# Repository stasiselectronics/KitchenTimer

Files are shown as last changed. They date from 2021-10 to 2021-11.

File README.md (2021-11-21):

# KitchenTimer

Welcome to the source files!

Here you can find all the files and folders needed to replicate or redesign this project!

This circuit board is designed to bring together a WiFi enabled microcontroller with a 4 character segmented LED display. 

# Current Status

I have recieved the first round of boards and began prototyping the electronics assembly.

The firmwware has some more work needed before it can display numbers and adjust brightness.

The board has a few things that need to be fixed before the next round of PCB fabrication.

I should try and get a PCB order soon, before the end of the year.

# Documentation

Not a lot of documentation except for the source files. If you have a question regarding this design, don't hesitate to open an issue on this repository

# Licenses

The design files for this project are covered under 

CERN-OHL-S

Cern Open Hardware License - Strongly Reciprocal

[View Full License Text](https://ohwr.org/cern_ohl_s_v2.pdf)

## Folder Structure

The project is separated into main categories at the root of the project folder. I use "Hardware Files" to hold all of the printed circuit board design files. I also use some other descriptive names and keep them consistent amongst projects:

- **Enclosure Files** : 3D printed or somehow otherwise fabricated. All the files needed for the box the project might end up in.
- **Firmware Files** : The code for any microcontrollers that might end up on the boards. 
- **Mechanical Files** : Any CAD files for fabricating parts for the project. 

## Libraries

The KiCAD project has a project specific library that can be used for keeping the custom designed footprints and symbols.

By default it isn't a global library, so if you would like to use the footprints or symbols in another project be sure to change it to a "global" library.

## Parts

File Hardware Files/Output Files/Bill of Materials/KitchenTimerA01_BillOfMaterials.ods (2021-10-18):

KitchenTimer |  |  | Bill Of Materials
PCBA Revision |  |  | A01
Item | Qty | Designator | Value | Part 1 MF | Part 1 MPN | Part 1 Ordering Code
1 | 2 | C10 C12 | 220nF 1206 Capacitor | YAGEO | CC1206KKX7R9BB224 | C107186 | ☐
2 | 8 | C1 C3-C8 C11 | 1 uF 0805 Capacitor | Samsung Electro-Mechanics | CL31B105KCHNNNE | C13832 | ☐
3 | 3 | C2 C9 C13 | 10uF 1206 Capacitor | Samsung Electro-Mechanics | CL31B106KAHNNNE | C14860 | ☐
4 | 1 | J1 | 2.54mm Male PCB Header | Ckmtw(Shenzhen Cankemeng) | B-2100S04P-A110 | C124378 | ☐
5 | 1 | J2 | MicroUSB | Korean Hroparts Elec | U-F-M5DD-Y-L | C91146 | ☐
6 | 1 | LED1 | Blue 4 Char LED 0.56" (CA) | SUNLIGHT | SLR0564DBA4BD | C225950 | ☐
7 | 5 | Q1-Q5 | PFET 1V 250uA 4A SOT-23 | Diodes Incorporated | DMG3415U-7 | C96616 | ☐
8 | 6 | R1 R2 R8-R11 | 10k 0805 Resistor | YAGEO | RC0805FR-0710KL | C84376 | ☐
9 | 5 | R3-R7 | 10k 0603 Resistor | YAGEO | RC0603FR-0710KL | C98220 | ☐
10 | 9 | R12-R20 | 10R 0603 Resistor | YAGEO | RC0603FR-0710RL | C109318 | ☐
11 | 2 | SW1 SW2 | SPST 50mA @ 12VDC SMD, 6.0x3.5x5.0mm | HYP (Hongyuan Precision) | 1TS002B-1900-4300-CT | C318823 | ☐
12 | 4 | SW3-SW6 | SPST 50mA @ 12VDC SMD, 6.0x6.0x5.0mm | HYP (Hongyuan Precision) | 1TS005F-2500-5001 | C255812 | ☐
13 | 1 | U4 | 15V 1.25V @ 1A Fixed 3.3V SOT-223 (LDO) | Diodes Incorporated | AZ1117H-3.3TRE1 | C92517 | ☐
14 | 1 | U1 | ESP 8266 SMD Module | Espressif Systems | ESP-WROOM-02D | C473007 | ☐
15 | 2 | U2 U3 | 3.3V/5V Shift Register SOIC 16 | Nexperia | 74HC595D | C5947 | ☐

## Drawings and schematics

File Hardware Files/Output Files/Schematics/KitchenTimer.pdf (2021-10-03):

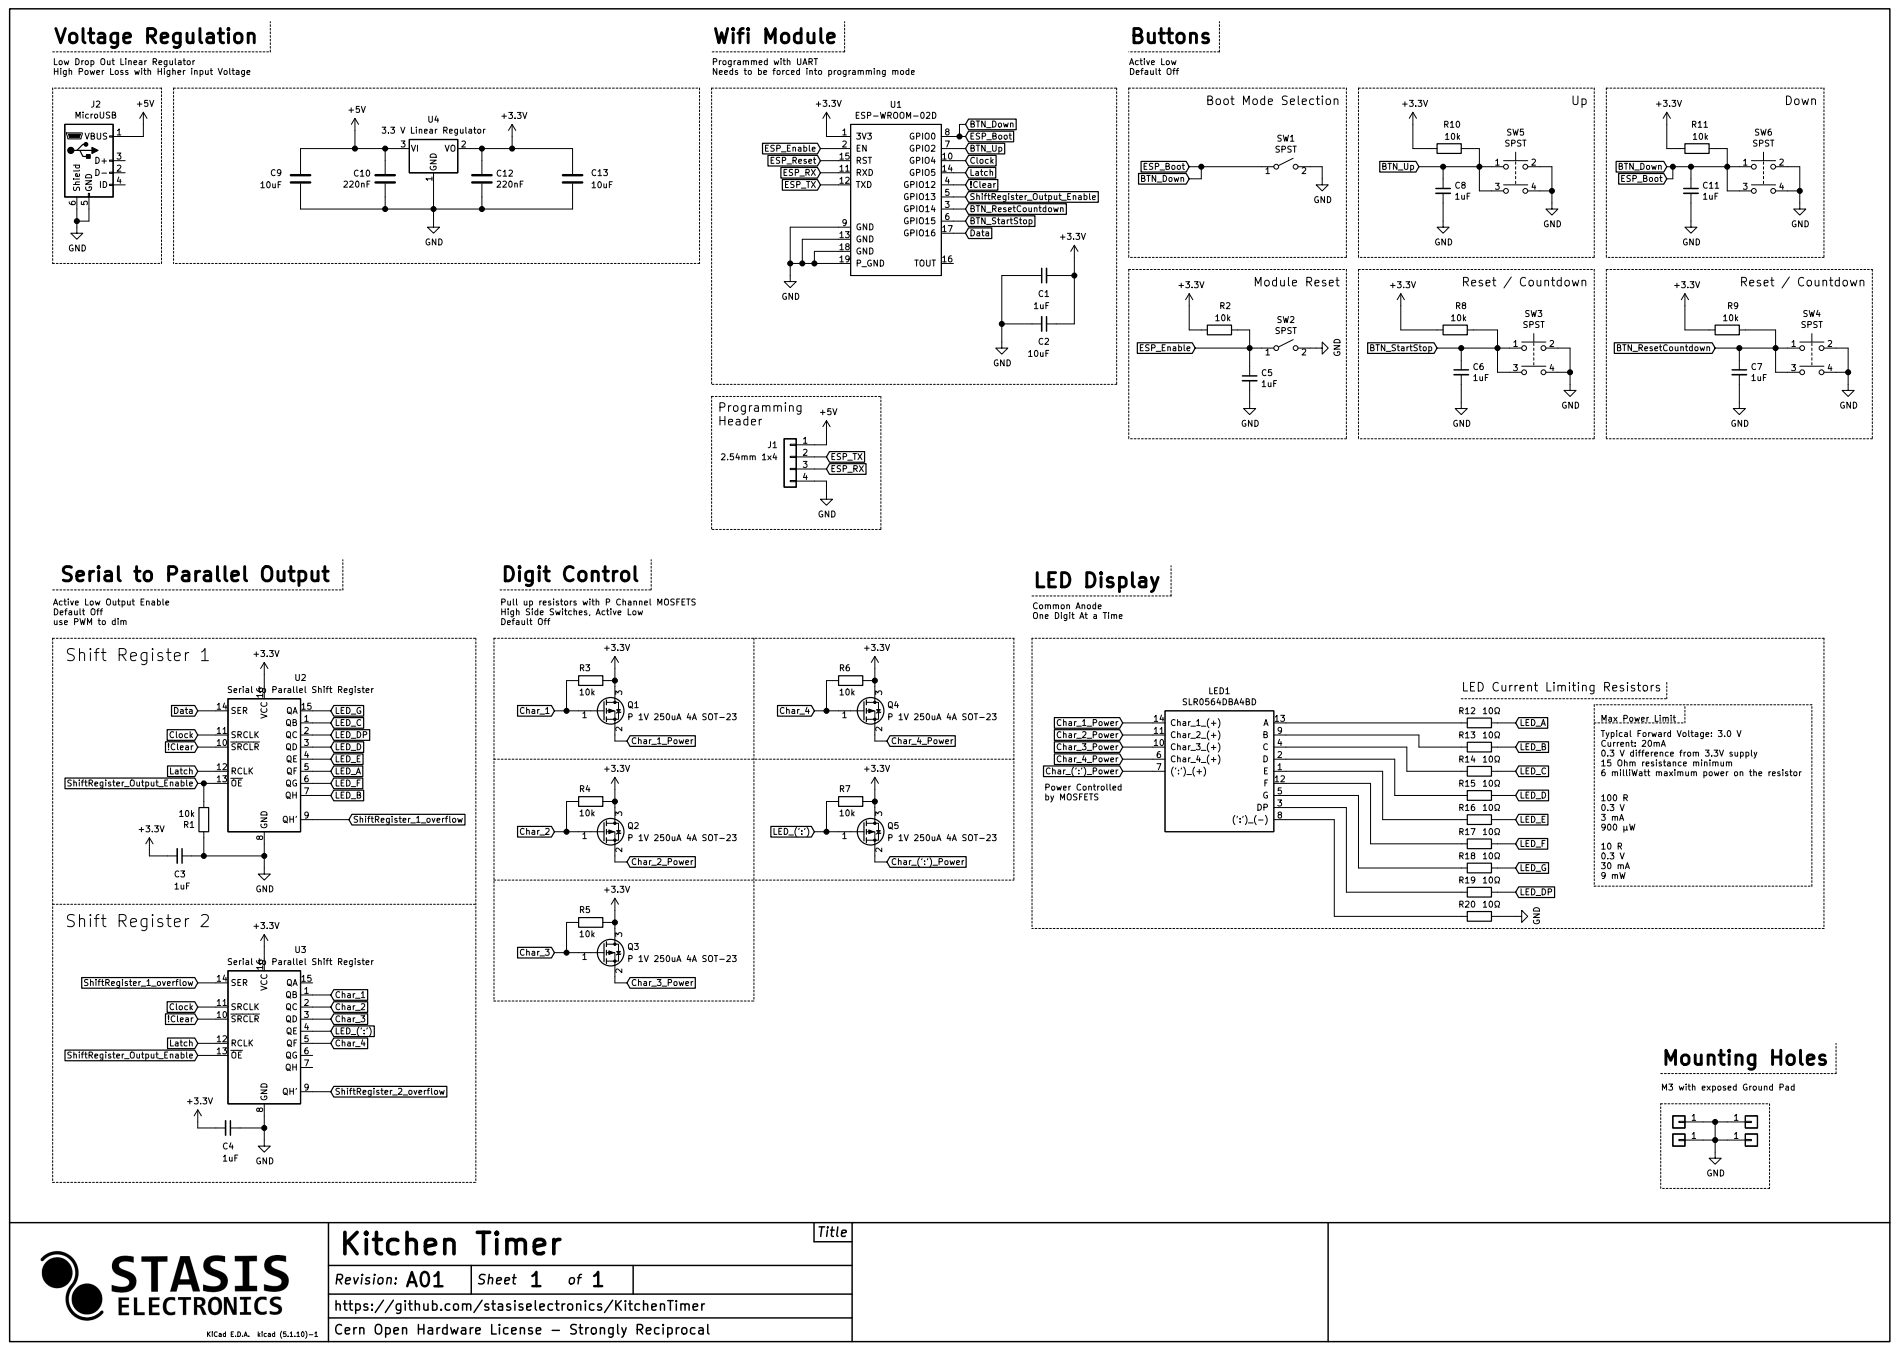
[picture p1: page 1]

Low Drop Out Linear Regulator
High Power Loss with Higher input Voltage

Programmed with UART
Needs to be forced into programming mode

8 QH' 9 U2 Serial to Parallel Shift Register GND GND

6 milliWatt maximum power on the resistor Max Power Limit Serial to Parallel Output

High Side Switches, Active Low

Common Anode One Digit At a Time

LED Current Limiting Resistors

Typical Forward Voltage: 3.0 V Current: 20mA

0.3 V difference from 3.3V supply 15 Ohm resistance minimum

8 QH' 9 U3 Serial to Parallel Shift Register

M3 with exposed Ground Pad

Revision:
https://github.com/stasiselectronics/KitchenTimer

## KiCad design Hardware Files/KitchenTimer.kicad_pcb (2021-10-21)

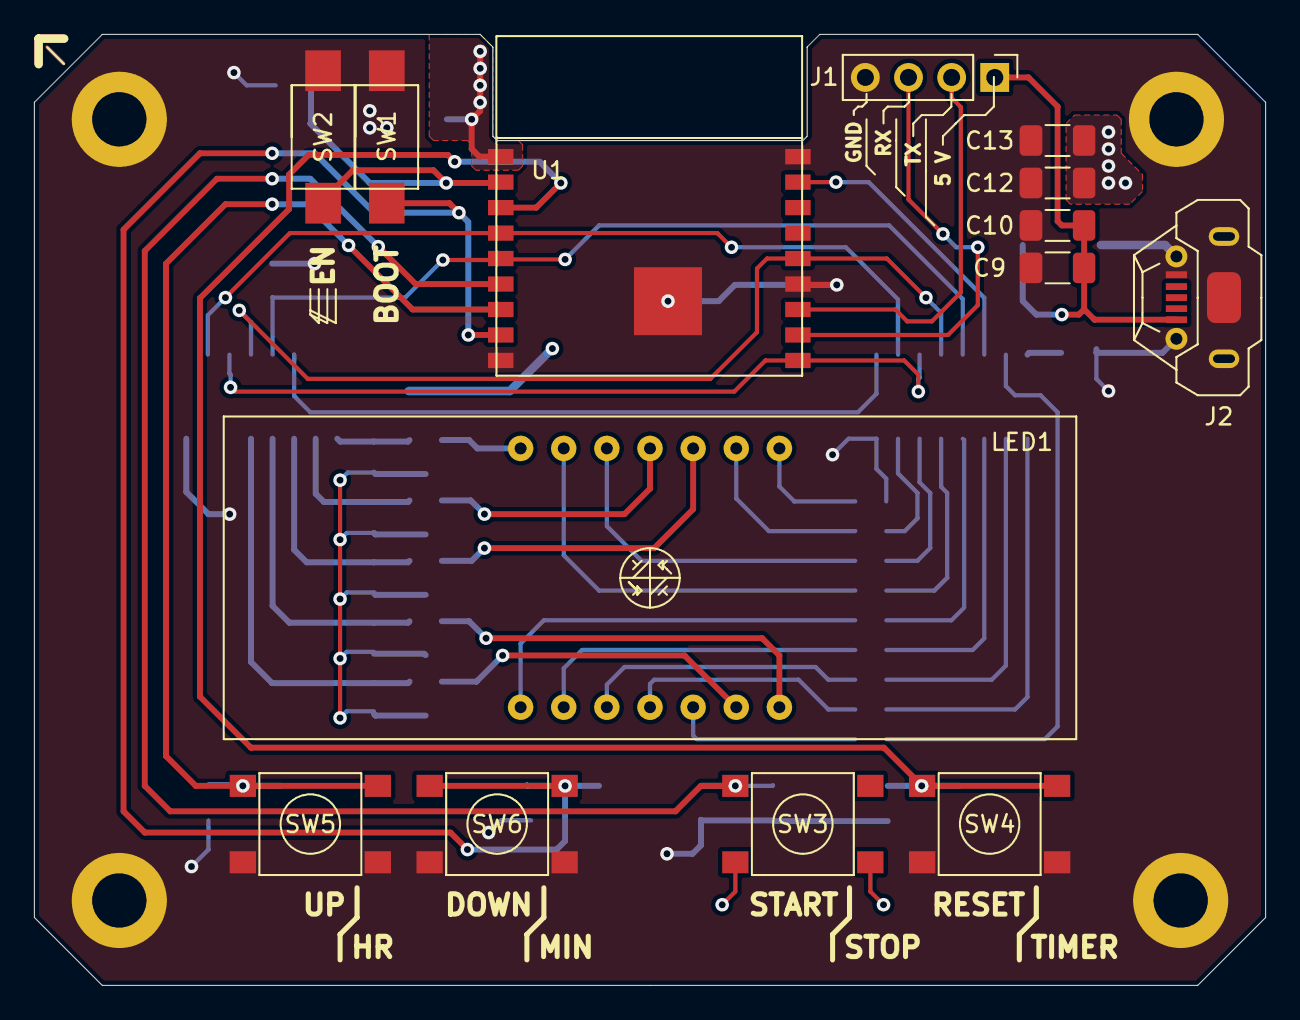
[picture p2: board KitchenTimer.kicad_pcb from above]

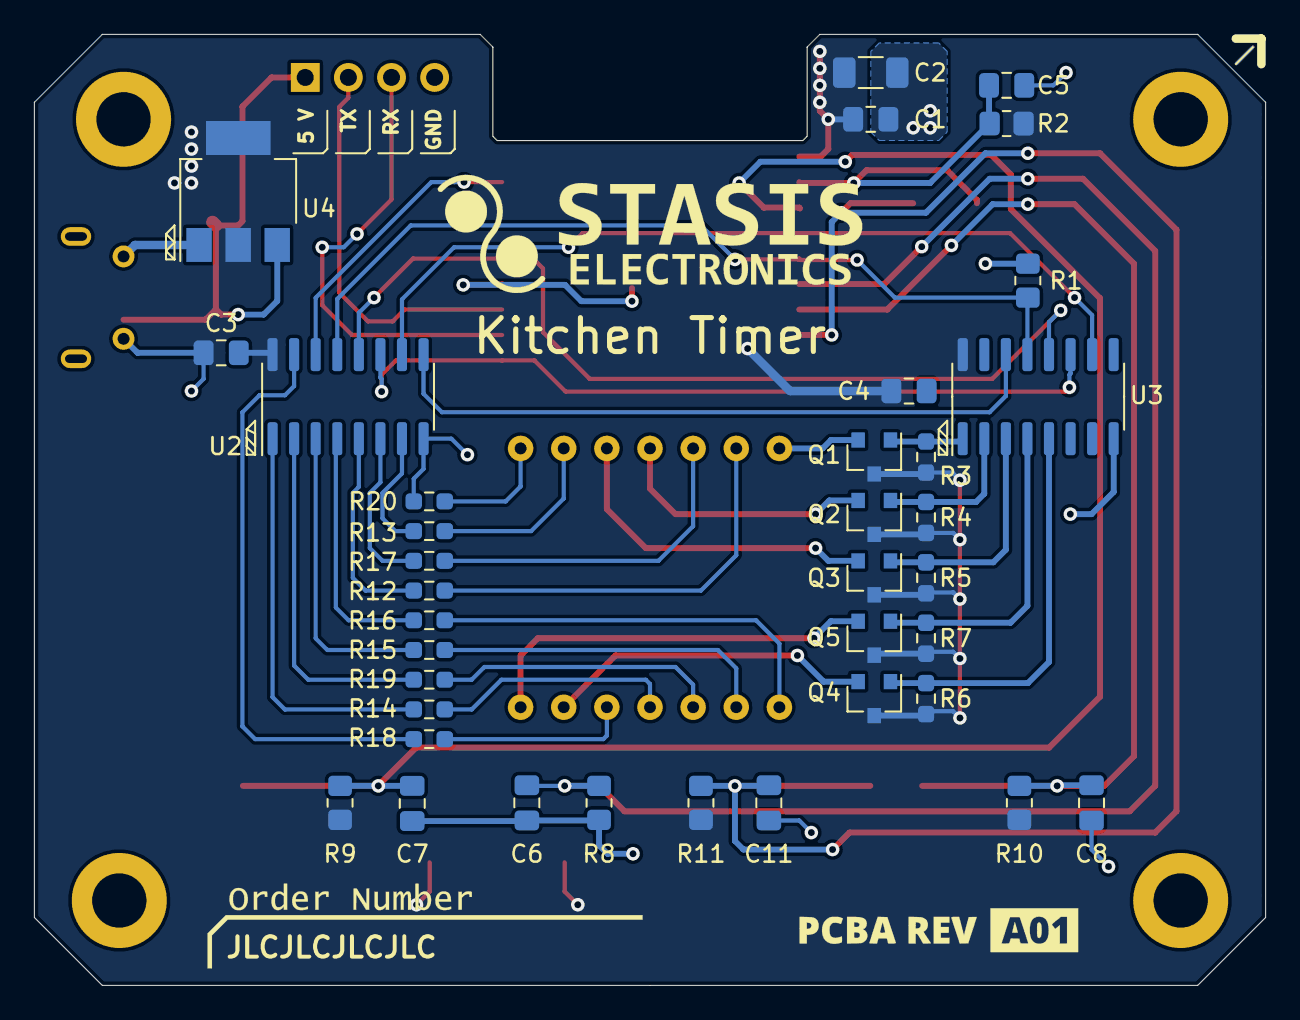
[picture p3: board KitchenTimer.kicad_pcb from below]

Board: 2 copper layers, 72.5 x 56.0 mm, 55 parts (37 on the bottom side), 43 nets.

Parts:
C1, C3, C4, C5, C6, C7, C8, C11: 1uF; C_0805_2012Metric_Pad1.18x1.45mm_HandSolder
C2, C9, C13: 10uF; C_1206_3216Metric_Pad1.33x1.80mm_HandSolder
C10, C12: 220nF; C_1206_3216Metric_Pad1.33x1.80mm_HandSolder
J1: 2.54mm 1x4; PinHeader_1x04_P2.54mm_Vertical
J2: MicroUSB; U-F-M5DD-Y-L
J3, J4, J5, J6: Mounting Hole; MountingHole_3.2mm_M3_DIN965_Pad
LED1: Blue 4 Char LED 0.56" (CA); SLR0564DBA4BD
Q1, Q2, Q3, Q4, Q5: PFET 1V 250uA 4A SOT-23; SOT-23
R1, R2, R8, R9, R10, R11: 10k; R_0805_2012Metric_Pad1.20x1.40mm_HandSolder
R3, R4, R5, R6, R7: 10k; R_0603_1608Metric_Pad0.98x0.95mm_HandSolder
R12, R13, R14, R15, R16, R17, R18, R19, R20: 10Ω; R_0603_1608Metric_Pad0.98x0.95mm_HandSolder
SW1, SW2: SPST; PTS636_SM25F_SMTR_LFS
SW3, SW4, SW5, SW6: SPST; PTS645SK50SMTR92LFS
U1: ESP-WROOM-02D
U2, U3: Serial to Parallel Shift Register; SOIC-16_3.9x9.9mm_P1.27mm
U4: 3.3 V Linear Regulator; SOT-223-3_TabPin2

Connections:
!Clear: U1.4, U2.10, U3.10
+3V3: C1.2, C2.1, C3.1, C4.1, C12.1, C13.1, Q1.3, Q2.3, Q3.3, Q4.3, Q5.3, R2.1, R3.2, R4.2, R5.2, R6.2, R7.2, R9.1, R10.1, R11.1, SW3.2, SW3.4, U1.1, U2.16, U3.16, U4.2
+5V: C9.1, C10.1, J1.1, J2.1, U4.3
BTN_Down: C11.1, R11.2, SW1.1, SW6.1, SW6.3, U1.8
BTN_ResetCountdown: C7.1, R9.2, SW4.1, SW4.3, U1.3
BTN_StartStop: C6.1, R8.1, SW3.1, SW3.3, U1.6
BTN_Up: C8.1, R10.2, SW5.1, SW5.3, U1.7
Char_1: Q1.1, R3.1, U3.1
Char_1_Power: LED1.14, Q1.2
Char_2: Q2.1, R4.1, U3.2
Char_2_Power: LED1.11, Q2.2
Char_3: Q3.1, R5.1, U3.3
Char_3_Power: LED1.10, Q3.2
Char_4: Q4.1, R6.1, U3.5
Char_4_Power: LED1.6, Q4.2
Char_(':')_Power: LED1.7, Q5.2
Clock: U1.10, U2.11, U3.11
Data: U1.17, U2.14
ESP_Enable: C5.1, R2.2, SW2.1, U1.2
ESP_RX: J1.3, U1.11
ESP_TX: J1.2, U1.12
GND: C1.1, C2.2, C3.2, C4.2, C5.2, C6.2, C7.2, C8.2, C9.2, C10.2, C11.2, C12.2, C13.2, J1.4, J2.5, J2.6, J3.1, J4.1, J5.1, J6.1, R1.1, R8.2, R20.2, SW1.2, SW2.2, SW4.2, SW4.4, SW5.2, SW5.4, SW6.2, SW6.4, U1.9, U1.13, U1.18, U1.19, U2.8, U3.8, U4.1
LED_(':'): Q5.1, R7.1, U3.4
LED_A: R12.2, U2.5
LED_B: R13.2, U2.7
LED_C: R14.2, U2.1
LED_D: R15.2, U2.3
LED_DP: R19.2, U2.2
LED_E: R16.2, U2.4
LED_F: R17.2, U2.6
LED_G: R18.2, U2.15
Latch: U1.14, U2.12, U3.12
unnamed: LED1.1, R16.1
unnamed: LED1.2, R15.1
unnamed: LED1.3, R19.1
unnamed: LED1.4, R14.1
unnamed: LED1.5, R18.1
unnamed: LED1.8, R20.1
unnamed: LED1.9, R13.1
unnamed: LED1.12, R17.1
unnamed: LED1.13, R12.1
ShiftRegister_1_overflow: U2.9, U3.14
ShiftRegister_Output_Enable: R1.2, U1.5, U2.13, U3.13

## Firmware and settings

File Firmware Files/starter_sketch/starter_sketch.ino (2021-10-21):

// Header files to include
#include <ESP8266WiFi.h>

// GPIO Pin Definitions
// Changing these will affect the board's functionality, do so at your own risk!
#define LATCH 5
#define CLOCK 4
#define DATA 16
#define SWITCH 14
#define CLEAR 12
#define OUTPUTENABLE 13


void setup() {
  Serial.begin(115200);                // begin Serial port and set the baud rate to 115200, feel free to change this if you want
  Serial.print("\n\n\n");              // helps to clear the application dialogue and the ESP8266's boot dialogue

  // GPIO Port Configuration
  Serial.println("Initializing Pins");
  pinMode(LATCH, OUTPUT);
  pinMode(CLOCK, OUTPUT);
  pinMode(DATA, OUTPUT);
  pinMode(CLEAR, OUTPUT);
  pinMode(OUTPUTENABLE, OUTPUT);
  pinMode(SWITCH, INPUT);

  // Set initial pin conditions
  digitalWrite(CLEAR, HIGH);  // Active Low
  digitalWrite(OUTPUTENABLE, LOW);  // Active Low

  Serial.println("Finished Setup, Starting loop");
}

void loop() {
  ESP.wdtFeed();  // Feed watchdog timer just in case, since we are doing nothing

  // Example of how to write data to the LEDs
  //digitalWrite(LATCH, LOW);
  //shiftOut(DATA, CLOCK, MSBFIRST, led_value);
  //digitalWrite(LATCH, HIGH);
}

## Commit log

2021-09-26 Change project name to KitchenTimer
    [KitchenTimer.kicad_pcb, KitchenTimer.sch]
2021-09-26 update library
    [KitchenTimer.sch]
2021-09-26 add 7 segment led symbol
2021-09-26 add led display and driver circuit
    [KitchenTimer.sch]
2021-09-26 add esp8266
    [KitchenTimer.sch]
2021-09-26 add boost converter circuits
    [KitchenTimer.sch]
2021-09-26 update boost converter circuit
    [KitchenTimer.sch]
2021-09-26 add sub sheets
    [KitchenTimer.sch, KitchenTimer_Battery.sch, KitchenTimer_ESP.sch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]
2021-09-26 move circuits into subsheets
    [KitchenTimer.sch, KitchenTimer_Battery.sch, KitchenTimer_ESP.sch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]
2021-09-27 Adjust sheet properties and output schematics
2021-09-27 add voltage regulators
    [KitchenTimer.sch, KitchenTimer_Battery.sch, KitchenTimer_ESP.sch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]
2021-09-27 add up and down buttons
    [KitchenTimer.sch, KitchenTimer_Battery.sch, KitchenTimer_ESP.sch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]
2021-09-27 add voltage source selection for LEDs
    [KitchenTimer_LEDs.sch]
2021-09-27 remove extra pull down resistor
    [KitchenTimer_LEDs.sch]
2021-09-27 remove mosfet for ":" char current sink
    [KitchenTimer_LEDs.sch]
2021-09-27 add led display footprint
2021-09-27 update footprint for symbol
    [KitchenTimer_LEDs.sch]
2021-09-27 push components to PCB
    [KitchenTimer.kicad_pcb, KitchenTimer_Battery.sch, KitchenTimer_ESP.sch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]
2021-09-27 remove current limit resistors to each char
    [KitchenTimer.kicad_pcb, KitchenTimer_LEDs.sch]
2021-09-27 change resistors to 0805
    [KitchenTimer.kicad_pcb, KitchenTimer_LEDs.sch]
2021-09-27 fix ground naming
    [KitchenTimer.kicad_pcb, KitchenTimer_Battery.sch, KitchenTimer_ESP.sch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]
2021-09-27 update layout
    [KitchenTimer.kicad_pcb, KitchenTimer_ESP.sch, KitchenTimer_LEDs.sch]
2021-09-27 reorganize mosfets
    [KitchenTimer.kicad_pcb]
2021-09-27 layout mosfets
    [KitchenTimer.kicad_pcb, KitchenTimer_LEDs.sch]
2021-09-28 change architecture approach
    [KitchenTimer.kicad_pcb, KitchenTimer_LEDs.sch]
2021-09-29 update shift register
    [KitchenTimer_LEDs.sch]
2021-10-01 reduce complexity and improve layout
    [KitchenTimer.sch, KitchenTimer_Battery.sch, KitchenTimer_LEDs.sch]
2021-10-01 remove old files
    [KitchenTimer_Battery.sch, KitchenTimer_ESP.sch, KitchenTimer_LEDs.sch]
2021-10-01 add gnd connection
    [KitchenTimer.kicad_pcb]
2021-10-01 update footprint step file references
    [KitchenTimer.kicad_pcb]
2021-10-02 Fix designator issues
    [KitchenTimer.kicad_pcb, KitchenTimer.sch]
2021-10-02 reposition designators
    [KitchenTimer.kicad_pcb]
2021-10-03 fix shift register pin mapping and routing
    [KitchenTimer.kicad_pcb, KitchenTimer.sch]
2021-10-03 update schematic layout
    [KitchenTimer.sch]
2021-10-03 update components
    [KitchenTimer.kicad_pcb, KitchenTimer.sch]
2021-10-03 finalize layout
    [KitchenTimer.kicad_pcb, KitchenTimer.sch]
2021-10-03 finalize silkscreen layers
    [KitchenTimer.kicad_pcb]
2021-10-03 add gerber files
    [KitchenTimer-B_Cu.gbr, KitchenTimer-B_Mask.gbr, KitchenTimer-B_Paste.gbr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]
2021-10-03 add gerber zip
2021-10-03 finalize output files
    [KitchenTimer.kicad_pcb]
2021-10-03 add BOM
    [KitchenTimerA01_BillOfMaterials.ods]
2021-10-03 Finalize Items
    [KitchenTimer.kicad_pcb, KitchenTimer.sch]
2021-10-06 update 1µF Capacitors
    [KitchenTimer.sch]
2021-10-18 remove OC field
    [KitchenTimer.sch]
2021-10-18 update part info
    [KitchenTimer.sch]
2021-10-18 update bill of materials
    [KitchenTimerA01_BillOfMaterials.ods]
2021-10-21 Fix zone priority causing short to ground
    [KitchenTimer.kicad_pcb]
2021-10-21 switch IO to active high with pulldown to enable UART download
    [KitchenTimer.sch]
2021-10-21 fix which net is changed
    [KitchenTimer.sch]
2021-10-21 update pcb layout to fix IO15 needing pull down
    [KitchenTimer.kicad_pcb]
